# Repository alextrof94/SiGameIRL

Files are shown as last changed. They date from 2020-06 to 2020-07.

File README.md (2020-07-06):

# SiGameIRL 
Устройство для проведения "Своей игры" с использованием "SImulator".

Автор программы для ПК Владимир Хиль: https://vladimirkhil.com/si

На данный момент доступна v0.2, где кнопки игроков вызывают собственные прерывания, из-за чего их отработка происходит мгновенно. 
[_Для подробностей перейдите в папку v2_](/v2)

Возможно будет и v0.3, где я полностью откажусь от Arduino, но маловероятно, так как связка Arduino+STM32 работает отлично...

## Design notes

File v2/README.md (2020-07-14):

# SiGameIRL v0.2
Устройство для проведения "Своей игры" (SIGame) через "SImulator".

Автор программы для ПК Владимир Хиль: https://vladimirkhil.com/si

Это версия 0.2

Тестирование платы:
* https://www.youtube.com/watch?v=EU762Oh5ceg

Игровое тестирование:
* https://www.youtube.com/watch?v=C6XTehjXuXQ

# Что вам потребуется

## Ведущий

* STM32F103C8T6 "Blue pill" (не запаянная) + программатор STLink v2 (желательно для прошивки, работа с другими методами прошивки не гарантируются)
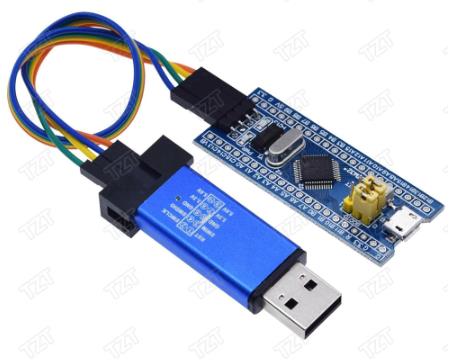
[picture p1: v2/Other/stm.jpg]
<dl></dl>

* Arduino nano (не запаянная)
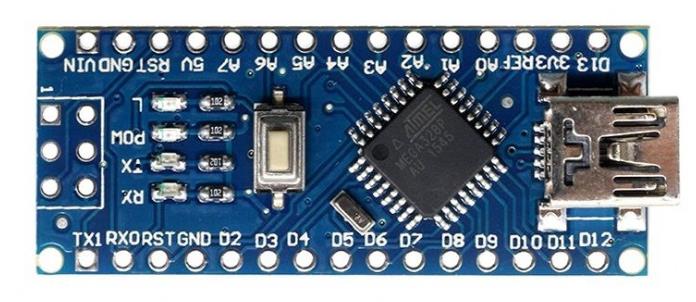
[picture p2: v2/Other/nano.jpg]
<dl></dl>

* Переключатель (опционально; 2 шт, либо 1 шт двухканальный, для разрыва цепи UART для программирования Arduino)

* Max7219 7-сегментный дисплей
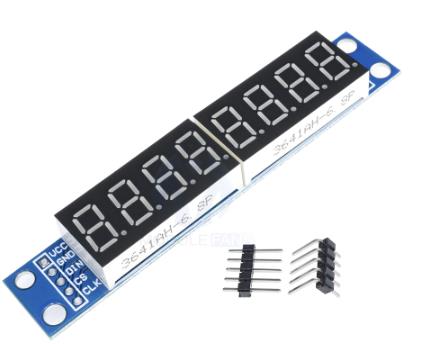
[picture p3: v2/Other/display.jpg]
<dl></dl>

* WS2812B светодиодная лента (60 светодиодов/м, 14 светодиодов с длинной 23.4см; можно также использовать и другую плотность светодиодов, общей длинной 23.4см, количество должно быть четным, например 32 светодиода при плотности 144с/м)
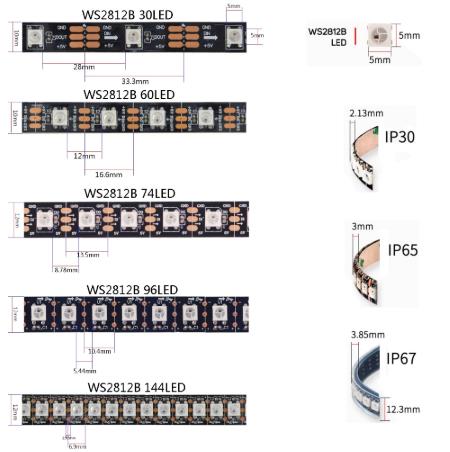
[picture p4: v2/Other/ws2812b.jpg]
<dl></dl>

* Кнопки 12х12мм с крышкой (13 шт)
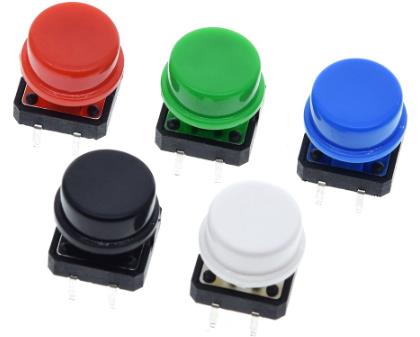
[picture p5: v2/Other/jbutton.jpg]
<dl></dl>

* Фоторезистор
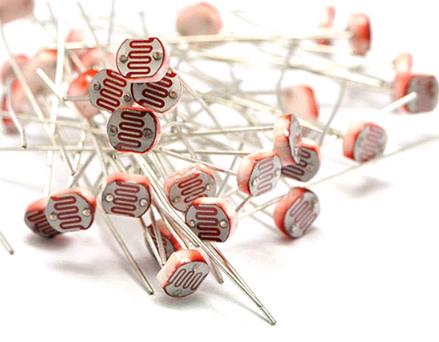
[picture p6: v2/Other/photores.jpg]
<dl></dl>

* Резистор 10000 Ом (11 шт)

* JST 3 pin (8 шт)
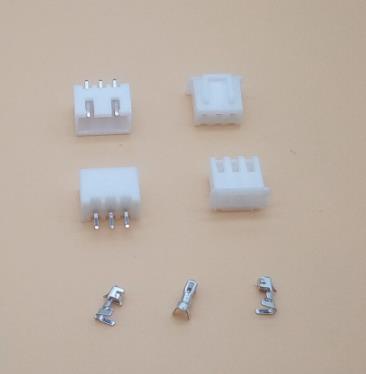
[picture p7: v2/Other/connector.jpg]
<dl></dl>

* Макетная плата (для пайки соединителей игроков) 

* Болты м3 (4 шт 6-12мм)

* Конденсатор электролитический (опционально, для впайки по питанию между +5в и землей)

* Резистор 300-1000 Ом и Светодиод (3 шт; опционально; __в модели нет для них отверстий__)

## Игрок (Умножаем на количество игроков, x8 обычно, но использовать можно и меньше)

* Кнопка 12x12мм (такие же как у судьи, но без крышек)
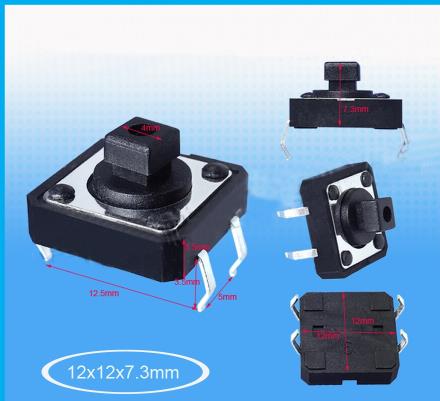
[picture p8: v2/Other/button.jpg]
<dl></dl>

* Резистор 300-1000 Ом

* Светодиоды (3 шт, можно и 1-2шт; цвет не важен; запаиваются параллельно)

* BLS 3 pin

* PLS 3 pin

# Собранный вид

* Собранный вариант (без питания от аккумуляторов)
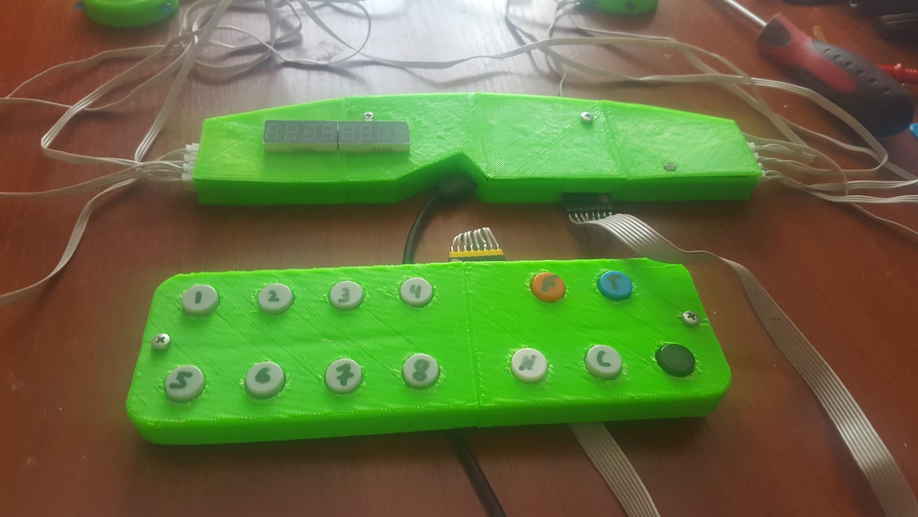
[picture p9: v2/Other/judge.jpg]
<dl></dl>
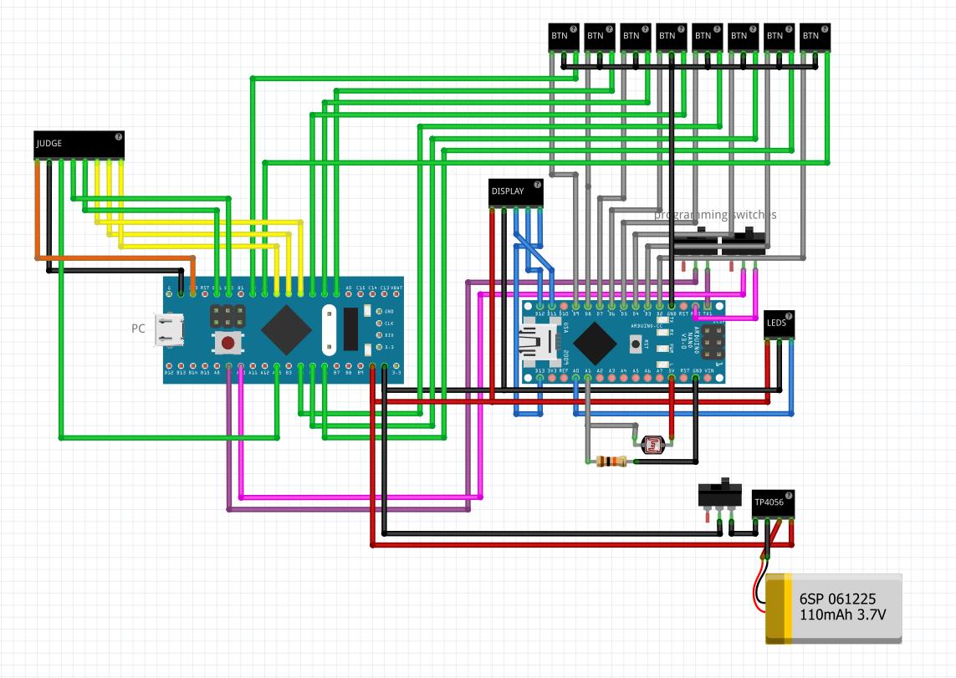
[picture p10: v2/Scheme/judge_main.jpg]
<dl></dl>
Светодиоды на модуле кнопок ведущего опциональны
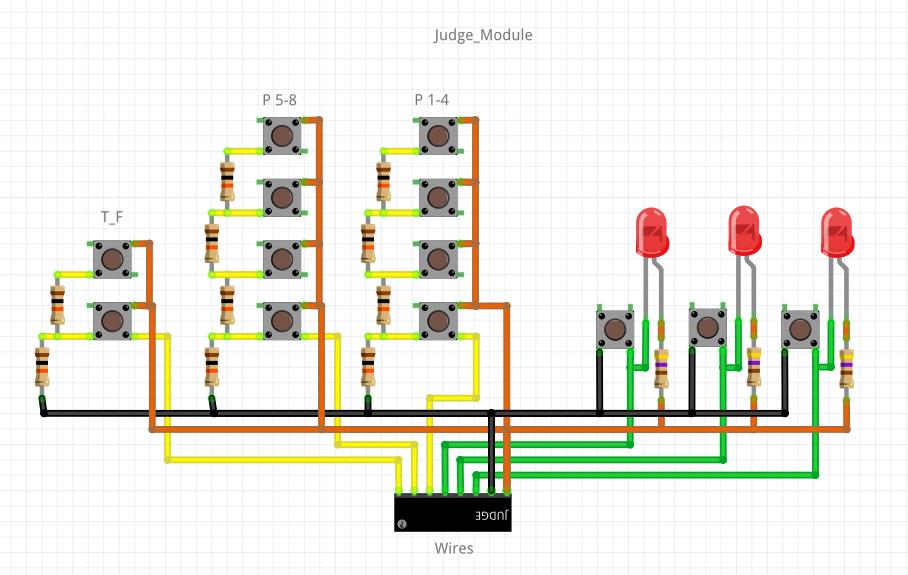
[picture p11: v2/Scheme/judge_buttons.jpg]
<dl></dl>

* Кнопка игрока
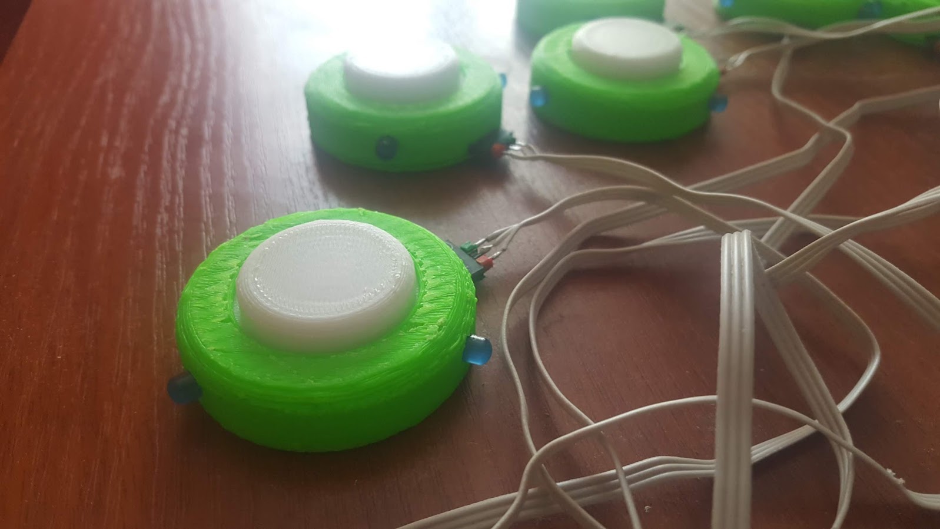
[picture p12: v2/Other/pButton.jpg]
<dl></dl>
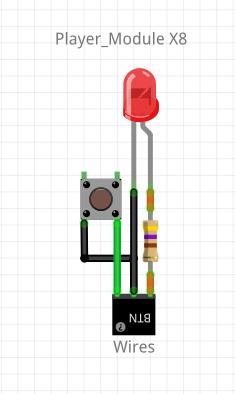
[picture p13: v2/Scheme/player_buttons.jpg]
<dl></dl>

* Внутри
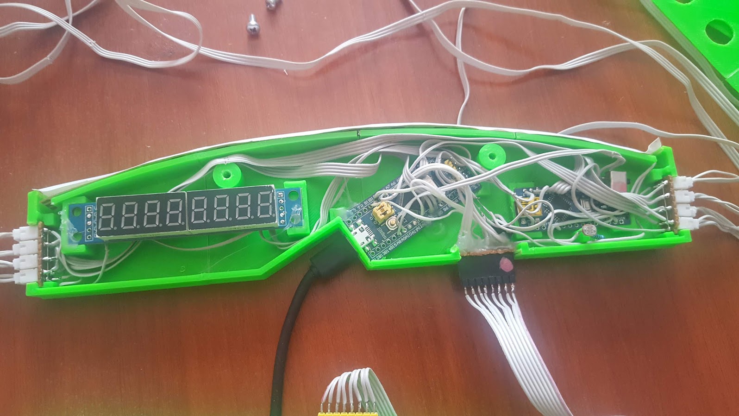
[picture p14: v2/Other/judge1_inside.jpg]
<dl></dl>
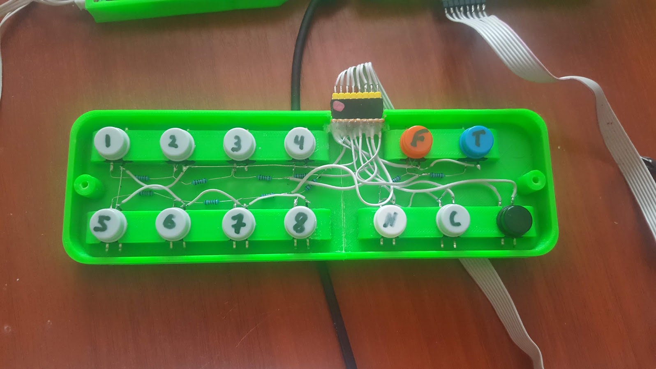
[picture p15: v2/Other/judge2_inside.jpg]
<dl></dl>
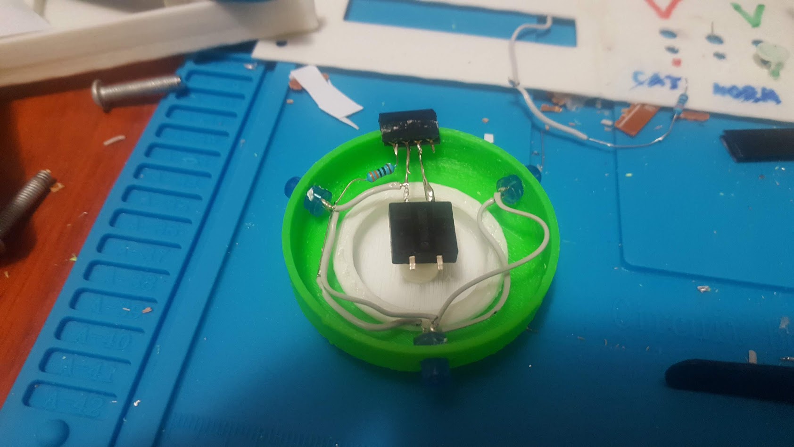
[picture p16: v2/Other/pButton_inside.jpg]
<dl></dl>

# Инструкция по использованию

## Первоначальная настройка

Как только вы подсоединяете питание, проходит проверка соединений (загораются кнопки, дисплей и индикатор). Затем вы переходите в первоначальную настройку, где вас просят ввести: 

* Время на реакцию игроков (когда они могут нажать кнопку для ответа) от 5 до 120 секунд, стандартных 10 секунд обычно достаточно, с привыкшими можно и 5 ставить.
* Время на ответ игрока от 5 до 120 секунд, стандартные 30 секунд для рядового человека - нормальное время, в любом случае, каждый раз ждать по 30 секунд не придется, так как на кнопки True/False можно нажать и во время ответа.
* Время на судейство от 5 до 120 секунд (стд. 120), оно введено для того, чтобы если ответ достаточно трудный и ведущему нужно уточнить что-либо - он может это делать во время судейства, игрок при этом уже должен молчать. 
* Время пенальти при фальшстарте от 0 до 5 секунд (стд. 2). Если игрок кликает свою кнопку до начала отсчета времени реакции - ему назначается штраф в секундах, когда его кнопка не будет реагировать на нажатия.
* Принудительная индексация игроков. В данный момент требуется по очереди нажать кнопки игрокам от 1 до Х, иначе им будут присвоены номера в зависимости от подключений и распайки коннекторов, и может возникнуть путаница. В случае игры со специальной версией СИмулятора - это может внести неразбериху. 

После ввода настроек - вы переходите в режим готовности, из которых вы можете запускать основные режимы игры с их подрежимами.
Также случайным образом выбирается выбирающий игрок. 

## Режимы

Всего есть 3 основных режима:

* Нормальный
* Кот в мешке / Аукцион
* Рандомизатор

Как только вы нажимаете на тему+сумму по выбору игрока вы выясняете какой тип вопроса перед вами, и от этого уже нажимаете Master/Special кнопку.

### Нормальный

1.1. Чтобы запустить нормальный режим - нажмите кнопку Master после прочтения вопроса (проигрывания музыки, отображения картинки).

1.2. После нажатия запустится подрежим реакции игроков. Игроки могут нажать свою кнопку и начать отвечать на вопрос. 

1.3. Если время вышло - вы вернетесь обратно в режим готовности. 

1.4. Если игрок нажал кнопку, то запустится подрежим его ответа, кнопка подсветится, на экране отобразится его индекс. Как только время пройдет - запустится подрежим судейства. Если же судья нажмет кнопку True - данный вопрос прекратится, и право хода перейдет к этому игроку. Если судья нажмет False - продолжится подрежим реакции игроков, но данный игрок не сможет еще раз нажать на кнопку во время этого вопроса.

1.5. Во время подрежима судейства опять же судья может нажать True/False с тем же результатом. И если время судейства вышло, False нажимается автоматически.

### Кот в мешке / Аукцион / Вопрос от спонсора

2.1. Чтобы запустить этот режим - надо нажать кнопку Special, если вы увидели вопрос-аукцион (вопрос со ставкой), кота в мешке (вопрос с секретом) или вопрос от спонсора (вопрос без риска).

2.2. После этого вы переходите в подрежим выбора отвечающего игрока, который осуществляется кнопками 1-8. После выбора игрока нажмите кнопку Master, чтобы перейти в подрежим ответа игрока как в пункте 1.4. только в случае с нажатием кнопки False судьей - вопрос тоже прекратится, и право выбора также перейдет к отвечавшему игроку.

### Рандомизатор

3.1. При удержании кнопки Reserved в течении секунды вы перейдете в режим рандомизации. Сначала от вас требуется выбрать игроков, которые участвуют в рандомизации при помощи кнопок 1-8. 

3.2. При нажатии кнопки Master из этих игроков случайно выбирается один. Если вы хотите передать ход этому игроку - нажмите кнопку True, иначе - нажмите False. При нажатии True/False вы автоматически перейдете в режим готовности.

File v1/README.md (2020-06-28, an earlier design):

# SiGameIRL
Устройство для проведения "Своей игры" (SIGame) через "SImulator".

Автор программы для ПК Владимир Хиль: https://vladimirkhil.com/si

Это версия 0.1. К сборке __НЕ рекомендуется__. Скоро займусь версией 0.2, где будут учтены проблемы данной версии. В данный момент нажатия кнопок считываются в цикле и бывают моменты, когда два игрока одновременно нажимают кнопки (период между считываниями кнопок 50-100 микросекунд), в видео тестирования в описании можно найти такой момент. 

Вторая версия будет основана на базе STM32F103C8T6 Blue Pill. Все кнопки будут иметь собственное прерывание (мгновенное отрабатывание).

Тестирование платы:
* https://www.youtube.com/watch?v=pi8g3aP3nV4

SiGameIRL собранный (тестирование в игре с 5-ю участниками; там маты, так что 16+):
* https://www.youtube.com/watch?v=th2ahZnA1qU

# Что вам потребуется

## Ведущий

### Для использования с питанием от ПК или блока питания

* Arduino nano (не запаянная)
<dl></dl>

* Max7219 7-сегментный дисплей
<dl></dl>

* WS2812B светодиодная лента (60 светодиодов/м, 10 светодиодов с длинной 16.7см, можно также использовать и другую плотность светодиодов, общей длинной 16.7см)
<dl></dl>

* Кнопки 6x6мм с длинным штоком (3 шт)
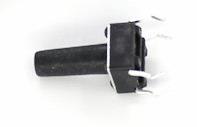
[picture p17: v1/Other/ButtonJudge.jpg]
<dl></dl>

* Резисторы 100-1000 Ом (3 шт)

* Светодиоды (3 шт; желательно красный-желтый-зеленый)

* Макетная плата (для пайки кнопок ведущего и соединителей игроков) 

* Болты м3 (4 шт 6-12мм)

### Для автономного питания от аккумуляторов 18650

* TP4056 с защитой
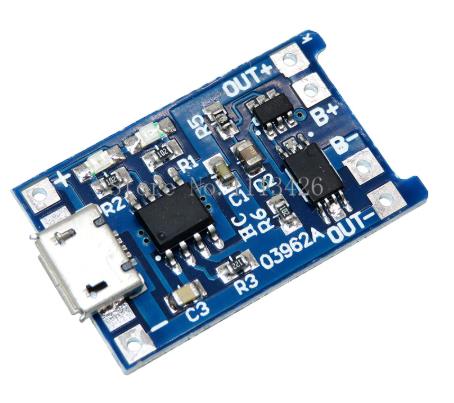
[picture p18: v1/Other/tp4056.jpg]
<dl></dl>

* 18650 держатель (1-2 шт; запаиваются ПАРАЛЛЕЛЬНО)
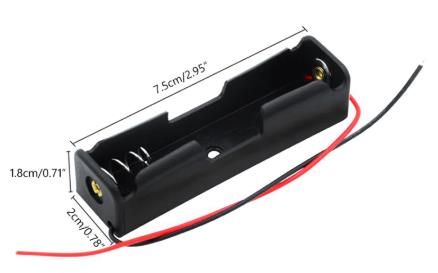
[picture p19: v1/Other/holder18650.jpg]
<dl></dl>

* Выключатель (10x15мм)
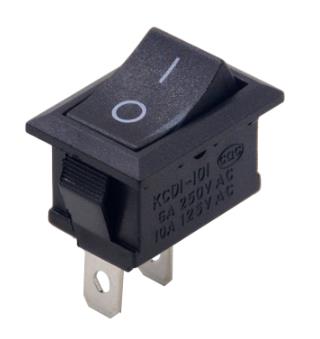
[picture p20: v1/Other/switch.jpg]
<dl></dl>

* Болты м3 (2 шт 6-20мм)

## Игрок (Умножаем на количество игроков, x8 обычно, но использовать можно и меньше)

* Кнопка 12x12mm
<dl></dl>

* Резистор 100-1000 Ом

* Светодиоды (3 шт, можно и 1-2шт; цвет не важен; запаиваются параллельно)

* JST 3 pin
<dl></dl>

* BLS 3 pin

* PLS 3 pin

# Собранный вид

* Собранный вариант (без питания от аккумуляторов)
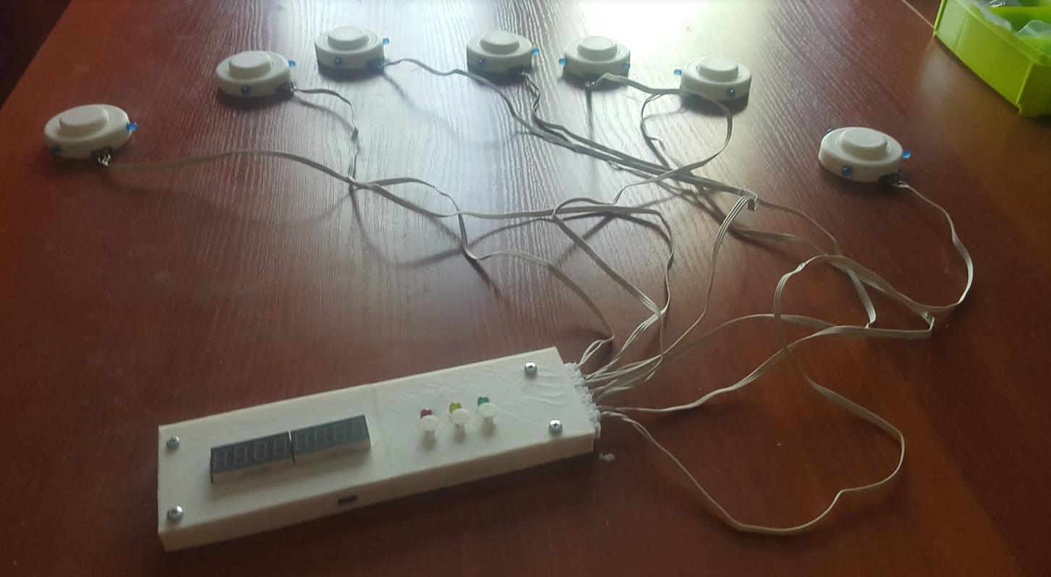
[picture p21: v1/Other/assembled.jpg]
<dl></dl>
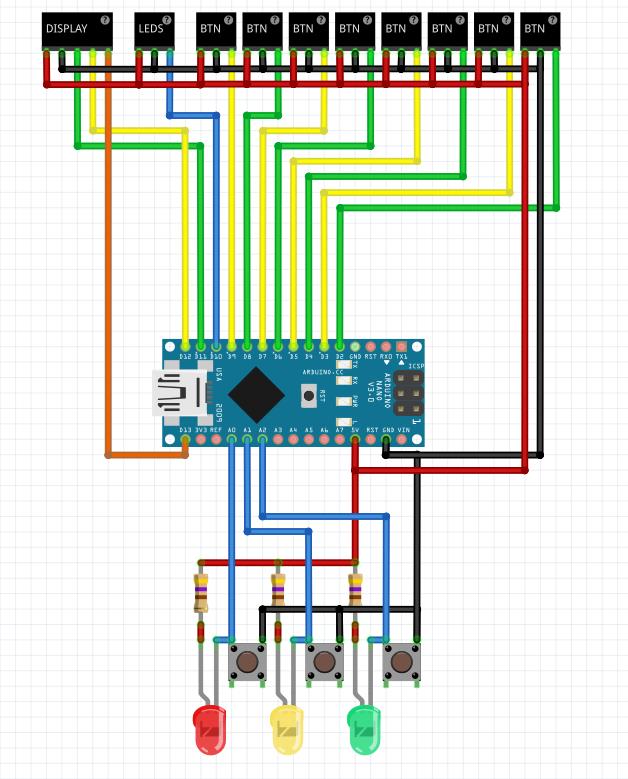
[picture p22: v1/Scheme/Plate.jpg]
<dl></dl>

* Кнопка игрока
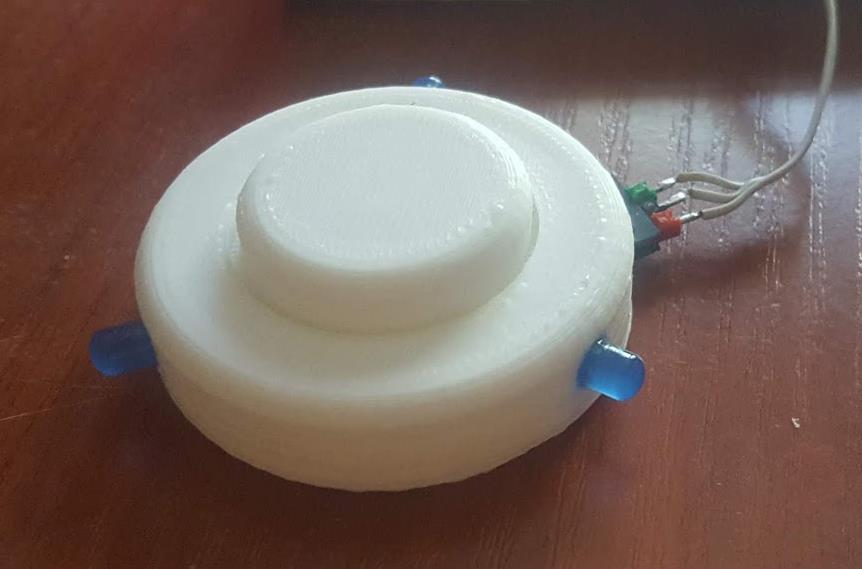
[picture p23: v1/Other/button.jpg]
<dl></dl>
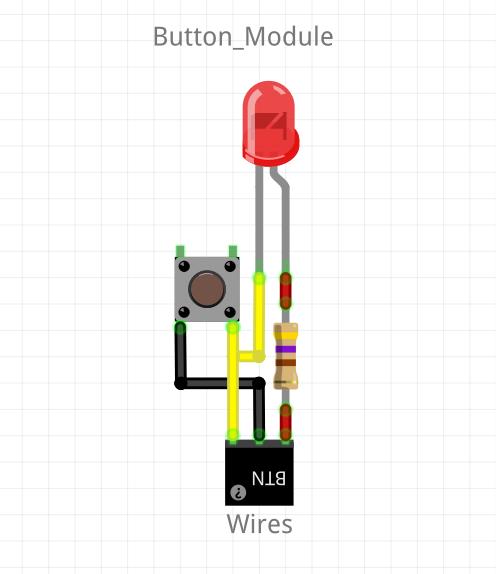
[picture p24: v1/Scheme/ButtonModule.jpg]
<dl></dl>

* Внутри
<dl></dl>

* Соединители игроков
<dl></dl>

* Кнопки ведущего
<dl></dl>

Все кнопки (сейчас) работают по следующей схеме: 
<dl></dl>

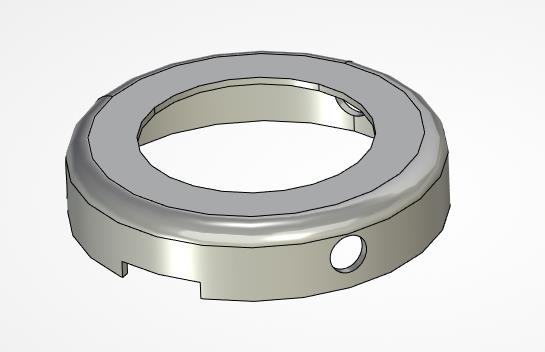
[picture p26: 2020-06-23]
v2/Models/Button/PartMiddle.jpg

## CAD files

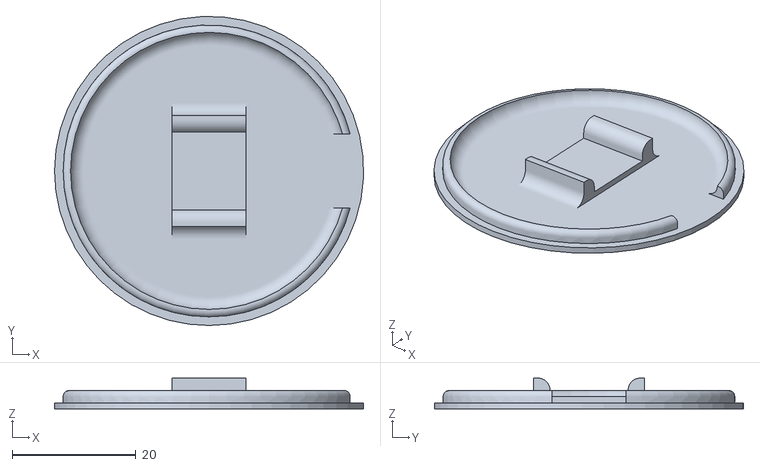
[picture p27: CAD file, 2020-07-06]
v2/Models/Button/SiGame_Button_B.stl
50.0 x 50.0 x 5.00

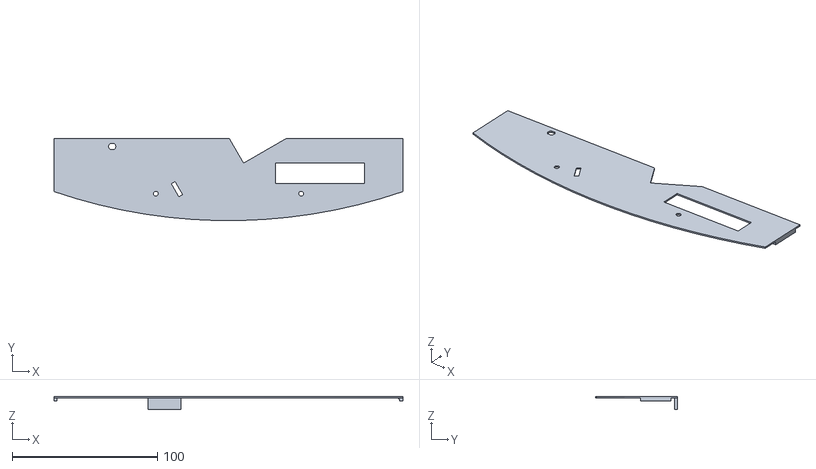
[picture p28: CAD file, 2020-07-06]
v2/Models/Judge/JudgeMaster_T.stl
240.0 x 56.4 x 9.19

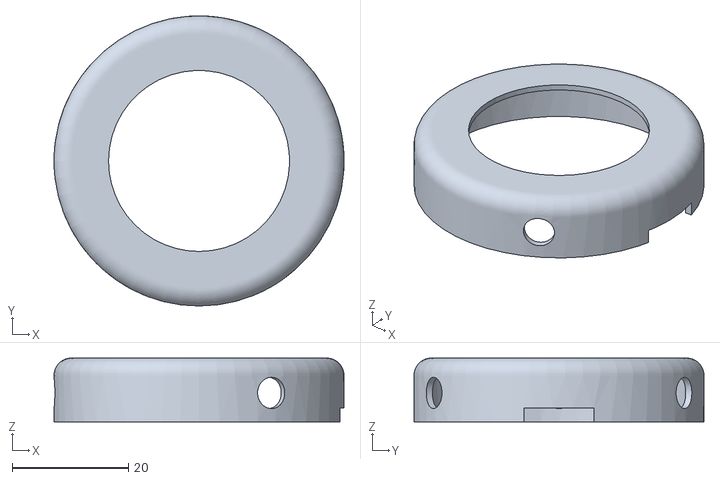
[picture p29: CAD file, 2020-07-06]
v2/Models/Button/SiGame_Button_M.stl
50.0 x 50.0 x 11.0

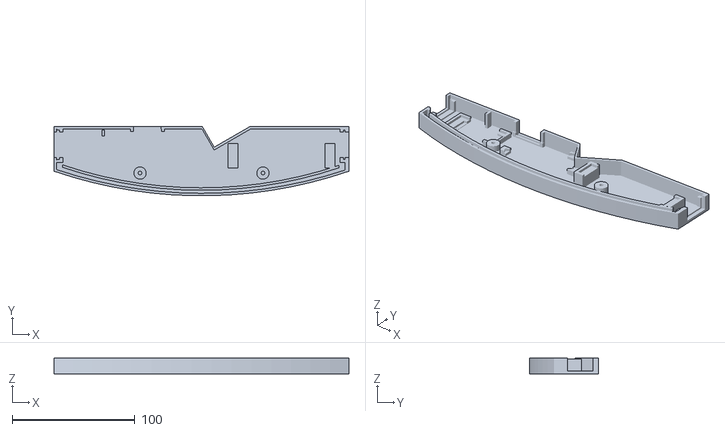
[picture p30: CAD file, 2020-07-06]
v2/Models/Judge/JudgeMaster_B.stl
240.0 x 56.4 x 13.0

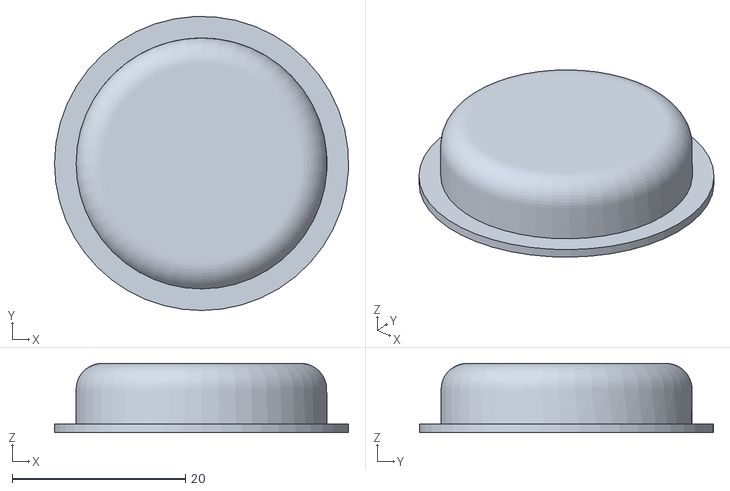
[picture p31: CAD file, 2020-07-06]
v2/Models/Button/SiGame_Button_T.stl
34.0 x 34.0 x 8.00

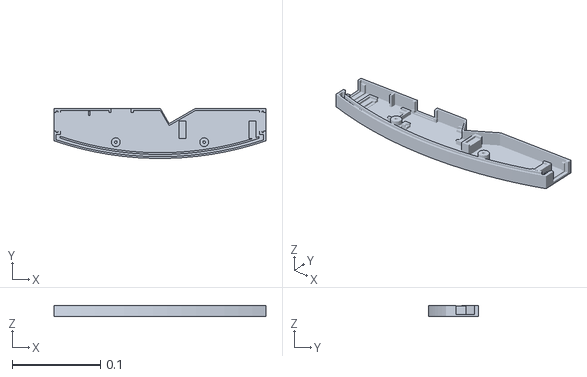
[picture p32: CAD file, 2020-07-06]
v2/Models/Judge/JudgeMaster.obj
0.24 x 0.0564 x 0.013

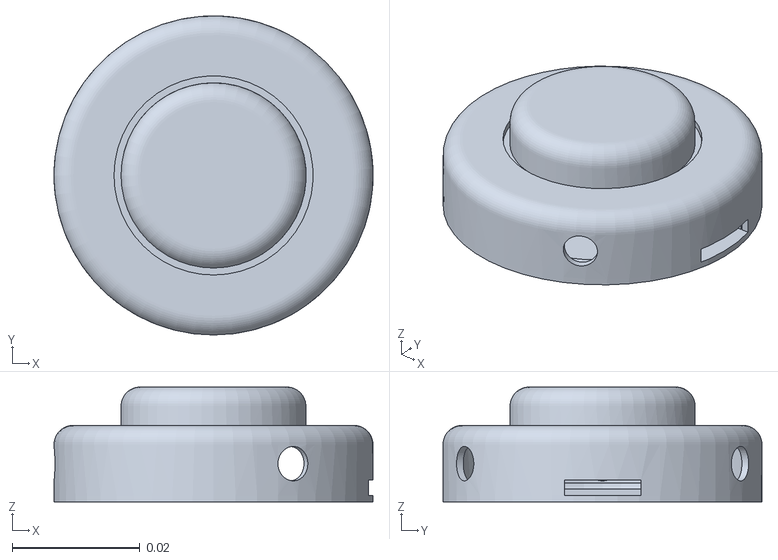
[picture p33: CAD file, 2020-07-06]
v2/Models/Button/SiGame_Button.obj
0.05 x 0.05 x 0.018

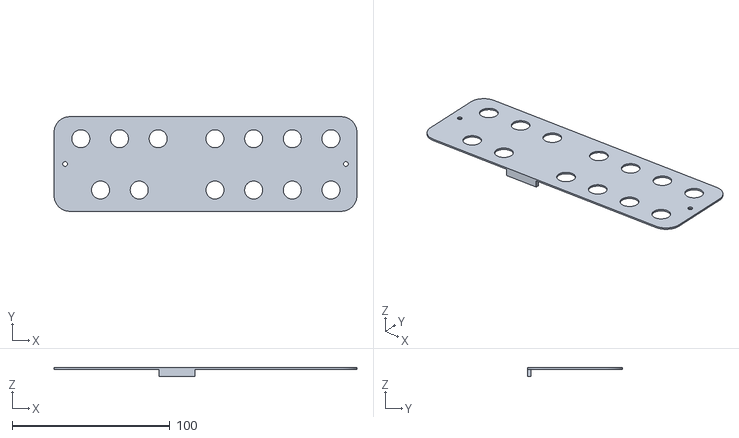
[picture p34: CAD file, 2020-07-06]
v2/Models/Judge/JudgeButtons_T.stl
192.0 x 60.0 x 5.40

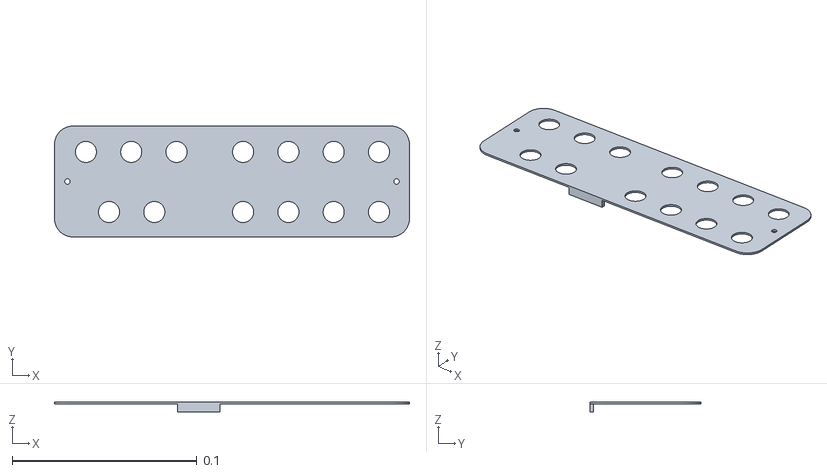
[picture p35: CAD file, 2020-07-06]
v2/Models/Judge/JudgeButtons.obj
0.192 x 0.06 x 0.0054

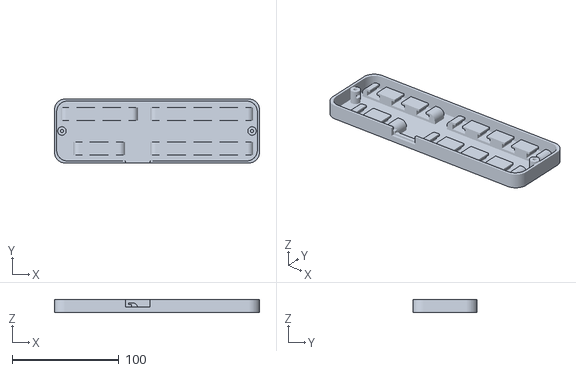
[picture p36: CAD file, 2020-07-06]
v2/Models/Judge/JudgeButtons_B.stl
192.0 x 60.0 x 12.0

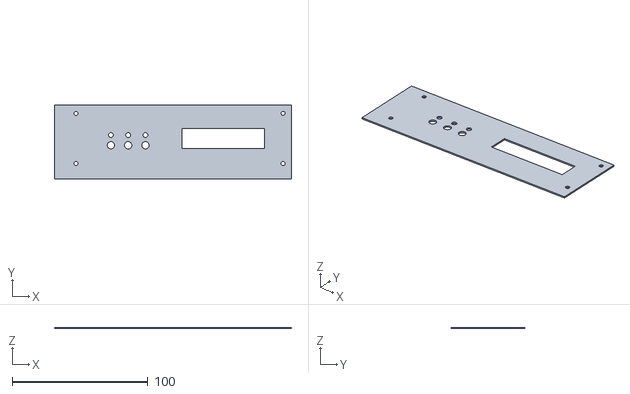
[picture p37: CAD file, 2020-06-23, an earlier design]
v1/Models/Judge/SiGame_Judge_Top.stl
174.4 x 54.6 x 1.00

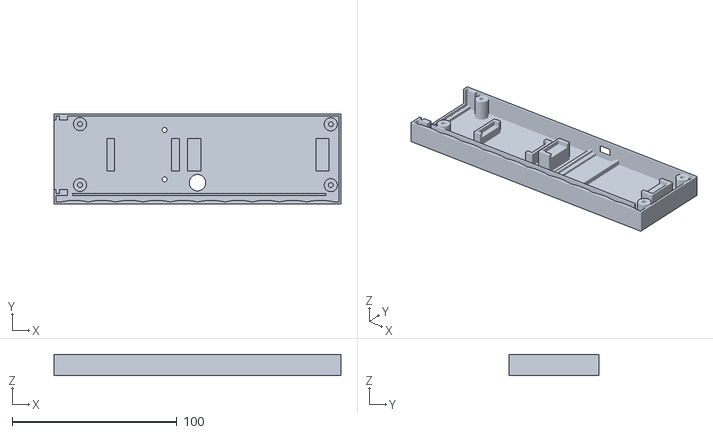
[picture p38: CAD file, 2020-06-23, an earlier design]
v1/Models/Judge/SiGame_Judge_Bottom.stl
174.4 x 54.6 x 13.0

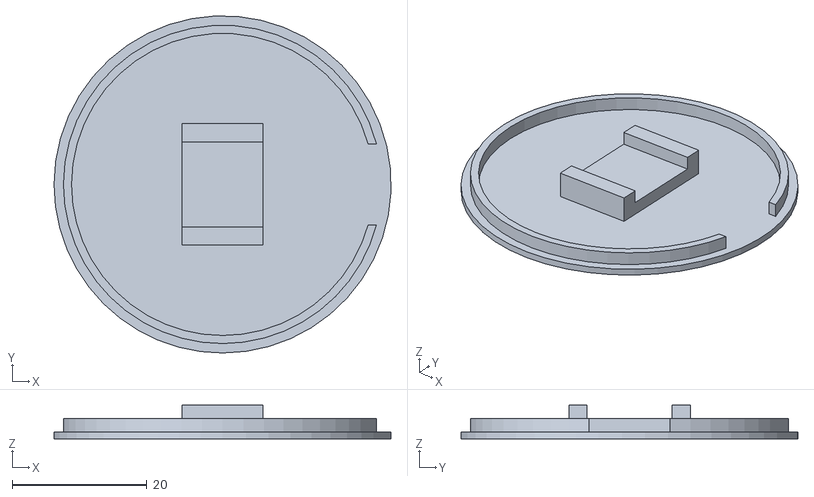
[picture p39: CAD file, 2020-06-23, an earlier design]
v1/Models/Button/SiGame_Button_Bottom.stl
50.0 x 50.0 x 5.00

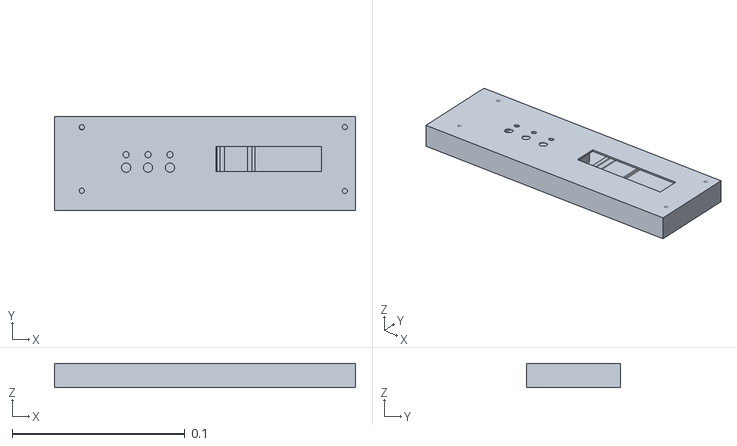
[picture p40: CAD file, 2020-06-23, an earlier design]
v1/Models/Judge/SiGame_Judge.obj
0.174 x 0.0546 x 0.014

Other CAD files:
v1/Models/Button/SiGame_Button_Middle.stl
v1/Models/Button/SiGame_Button_Top.stl
v1/Models/Button/SiGame_Button.obj
v1/Models/Judge/SiGame_Judge_Accum.stl
v1/Models/Button/SiGame_Button.dxf
v1/Models/Judge/SiGame_Judge.dxf
v2/Models/Button/SiGame_Button.dxf
v2/Models/Judge/JudgeButtons.dxf
v2/Models/Judge/JudgeMaster.dxf

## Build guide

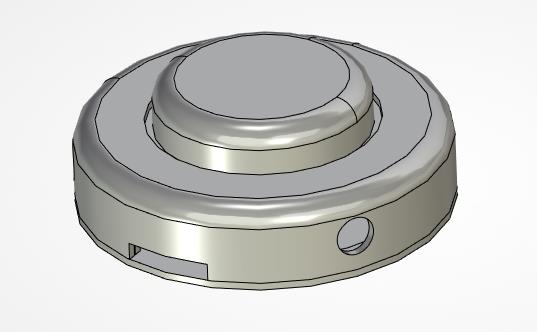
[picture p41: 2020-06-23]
v2/Models/Button/Assembled.jpg

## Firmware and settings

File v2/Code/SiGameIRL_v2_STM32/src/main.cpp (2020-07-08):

#include <Arduino.h>

const uint8_t PIN_PLAYERS[8] = {PB0, PA1, PA2, PA3, PB4, PB5, PB6, PA7}; // !!! SETUP THIS WITH YOUR SOLDERED BUTTONS (MUST BE IN PB0, PA1, PA2, PA3, PB4, PB5, PB6, PA7)

const uint8_t PIN_JUDGE_MASTER = PA15; // !!! SETUP THIS WITH YOUR SOLDERED BUTTONS (MUST BE IN PB10, PB11, PA15)
const uint8_t PIN_JUDGE_SPECIAL = PB10; // !!! SETUP THIS WITH YOUR SOLDERED BUTTONS (MUST BE IN PB10, PB11, PA15)
const uint8_t PIN_JUDGE_RESERVED = PB11; // !!! SETUP THIS WITH YOUR SOLDERED BUTTONS (MUST BE IN PB10, PB11, PA15)
const uint8_t PIN_JUDGE_A_T_F = PA6; // !!! SETUP THIS WITH YOUR SOLDERED BUTTONS (MUST BE IN PA4, PA5, PA6)
const uint8_t PIN_JUDGE_A_P_1_4 = PA4; // !!! SETUP THIS WITH YOUR SOLDERED BUTTONS (MUST BE IN PA4, PA5, PA6)
const uint8_t PIN_JUDGE_A_P_5_8 = PA5; // !!! SETUP THIS WITH YOUR SOLDERED BUTTONS (MUST BE IN PA4, PA5, PA6)

#define PC Serial
const uint32_t PC_BAUDTRATE = 115200;
#define ARD Serial1
const uint32_t ARD_BAUDTRATE = 115200;

#define COLOR_QUESTION 0x6600FF // purple
#define COLOR_ANSWERING 0x0000FF // blue 
#define COLOR_JUDGEMENT 0xFFFF00 // yellow
#define COLOR_ANSWER_TRUE 0x00FF00 // green
#define COLOR_ANSWER_FALSE 0xFF0000 // red

#define MODE_INITIALIZATION 100
#define MODE_SETTINGS 0
#define MODE_READY 1
#define MODE_QUESTION_NORMAL 2
#define MODE_QUESTION_CAT_SELECT_PLAYER 3
#define MODE_ANSWERING 6
#define MODE_JUDGEMENT 7
#define MODE_ROUND_END 8
#define MODE_RANDOM_SELECTING_PLAYERS 20
#define MODE_RANDOM_DO 21
uint8_t mode = MODE_INITIALIZATION;
bool isCatQuestion = false;
uint8_t modeOld = 255;
int answeringPlayer = -1;
int answeringPlayerOld = -1;

#define ROUND_END_STATUS_TIME_IS_UP 0
#define ROUND_END_STATUS_SKIPPED 1
#define ROUND_END_STATUS_ANSWERED 2
#define ROUND_END_STATUS_CAT_FALSE 3
uint8_t roundEndStatus = ROUND_END_STATUS_TIME_IS_UP;

class Button {
  protected:
    bool isPressedOld = false;
  public:
    uint8_t pin;  
    bool isPressed = false;
    bool isClicked = false;
    uint32_t pressTime = 0;
    uint32_t releaseTime = 0;
    uint32_t debounceTime = 50000; // 50 ms

    Button() {}

    void readState() {
      if (isPressed && !isPressedOld) {
        pressTime = micros();
      } else {
        if (!isPressed && isPressedOld) {
          releaseTime = micros();
          if (releaseTime - pressTime > debounceTime)
            isClicked = true;
        }
      }
      
      isPressedOld = isPressed;
    }

    bool clickNotProcessed() {
      if (isClicked) {
        isClicked = false;
        return true;
      } else
        return false;      
    };
};

class ButtonInterrupt: public Button {
  public:
    ButtonInterrupt() : Button() {}
    ButtonInterrupt(uint8_t inPin) {
      pin = inPin;
    };

    void readState() {
      isPressed = !digitalRead(pin);
      Button::readState();
    };

};

class ButtonAnalog : public Button {  
  private:
    uint16_t buf;
  public:
    uint16_t analogMin;
    uint16_t analogMax;

    ButtonAnalog() : Button() {}
    ButtonAnalog(uint8_t inPin, uint16_t inValueMin, uint16_t inValueMax) {
      pin = inPin;
      analogMin = inValueMin;
      analogMax = inValueMax;
    };

    void readState() {
      buf = analogRead(pin);
      if (buf >= analogMin && buf <= analogMax)
        isPressed = true;
      else
        isPressed = false;

      Button::readState();
    };
};

class Player {
  public:
    ButtonInterrupt button;
    uint32_t falseStartPenaltyTimer = 0;
    bool falseStartPenalty = false;
    bool canAnswer = false;
    uint8_t playerIndex = 255;
    uint8_t playerActive = false;

    Player() {};

    void reset() {
      canAnswer = true;
      falseStartPenalty = false;
    }
};
Player players[8];
uint8_t activePlayerCount = 0;

ButtonInterrupt jbtnMaster = ButtonInterrupt(PIN_JUDGE_MASTER);
ButtonInterrupt jbtnSpecial = ButtonInterrupt(PIN_JUDGE_SPECIAL);
ButtonInterrupt jbtnReserved = ButtonInterrupt(PIN_JUDGE_RESERVED);
ButtonAnalog jbtnTrue = ButtonAnalog(PIN_JUDGE_A_T_F, 400, 620);
ButtonAnalog jbtnFalse = ButtonAnalog(PIN_JUDGE_A_T_F, 900, 1023);
ButtonAnalog jbtnPS[8] = {
  ButtonAnalog(PIN_JUDGE_A_P_1_4, 200, 290),
  ButtonAnalog(PIN_JUDGE_A_P_1_4, 290, 480),
  ButtonAnalog(PIN_JUDGE_A_P_1_4, 480, 700),
  ButtonAnalog(PIN_JUDGE_A_P_1_4, 700, 1023),
  ButtonAnalog(PIN_JUDGE_A_P_5_8, 200, 290),
  ButtonAnalog(PIN_JUDGE_A_P_5_8, 290, 480),
  ButtonAnalog(PIN_JUDGE_A_P_5_8, 480, 700),
  ButtonAnalog(PIN_JUDGE_A_P_5_8, 700, 1023)
};


const uint32_t questionSecondsMax = 120;
uint32_t questionSeconds = 10;
uint32_t questionSecondsLeft;
uint32_t questionMsTimer;
uint32_t questionMsTimerLeft;

const uint32_t answerSecondsMax = 120;
uint32_t answerSeconds = 30;
uint32_t answerSecondsLeft;
uint32_t answerMsTimer;

const uint32_t judgeSecondsMax = 120;
uint32_t judgeSeconds = 120;
uint32_t judgeSecondsLeft;
uint32_t judgeMsTimer;

const uint32_t falseStartPenaltySecondsMax = 5;
uint32_t falseStartPenaltySeconds = 2;
bool falseStartPenaltyEnabled = true;
uint32_t falseStartPenaltyDelay = 2000;

void processPlayer(uint8_t playerIndex) {
  players[playerIndex].button.isPressed = !digitalRead(PIN_PLAYERS[playerIndex]);
  if (players[playerIndex].button.isPressed) {
    players[playerIndex].button.pressTime = micros();
    if (mode == MODE_READY) {
      if (falseStartPenaltyEnabled) {
        players[playerIndex].falseStartPenalty = true;
        players[playerIndex].falseStartPenaltyTimer = millis() + falseStartPenaltyDelay;
      }
    } else
    if (mode == MODE_QUESTION_NORMAL) {
      if (answeringPlayer == -1) {
        if (!players[playerIndex].falseStartPenalty && players[playerIndex].canAnswer)
          answeringPlayer = playerIndex; // attention
      }
    } else
    if (mode == MODE_ANSWERING || mode == MODE_JUDGEMENT)
    {
      if (falseStartPenaltyEnabled && answeringPlayer != playerIndex) { // attention
        players[playerIndex].falseStartPenalty = true;
        players[playerIndex].falseStartPenaltyTimer = millis() + falseStartPenaltyDelay;
      }
    }    
  }
  else {
    players[playerIndex].button.releaseTime = micros();
    players[playerIndex].button.isClicked = true;
  }
}

void P0_INT() {
  processPlayer(0);
}
void P1_INT() {
  processPlayer(1);
}
void P2_INT() {
  processPlayer(2);
}
void P3_INT() {
  processPlayer(3);
}
void P4_INT() {
  processPlayer(4);
}
void P5_INT() {
  processPlayer(5);
}
void P6_INT() {
  processPlayer(6);
}
void P7_INT() {
  processPlayer(7);
}

void JMASTER_INT() {
  jbtnMaster.readState();
}
void JSPECIAL_INT() {
  jbtnSpecial.readState();
}
void JRESERVED_INT() {
  jbtnReserved.readState();
}

void jbuttonsCheck() {
  jbtnTrue.readState();
  jbtnFalse.readState();
  for (uint8_t i = 0; i < 8; i++)
    jbtnPS[i].readState();
}

void sendToLeds(uint8_t needToLight, uint32_t color) {
  ARD.print('L');
  ARD.print((char)needToLight);
  ARD.print((char)((color >> 16) & 0xFF));
  ARD.print((char)((color >> 8) & 0xFF));
  ARD.println((char)(color & 0xFF));
}
void sendText(String str) {
  ARD.print('T');
  ARD.println(str);
}
void sendReset() {
  ARD.println('R');
}
void sendPlayer(uint8_t p, char state){
  ARD.print('P');
  ARD.print((char)p);
  ARD.println(state);
}


bool rEnable = true;
uint32_t displayUpdateTimer;
const uint32_t displayUpdateDelay = 1000; // ms
uint32_t ledsUpdateTimer;
uint32_t ledsUpdateDelay;

uint8_t ledstripLength = 0;
uint8_t initNeed = 1;
void modeInitialization() {
  if (ARD.available() > 3) {
    char cmd = ARD.read();
    if (cmd == 'L') {
      uint8_t k = 100;
      for (uint8_t i = 0; i < 3; i++) {
        ledstripLength += (ARD.read() - '0') * k;
        k /= 10;
      }
      initNeed--;
      ARD.print('K');
      PC.print("Log: ledstrip length "); PC.println(ledstripLength);
    }  
  }
  if (initNeed == 0) {
    mode = MODE_SETTINGS;
    digitalWrite(PC13, 0);
  }
}

uint8_t modeSettingsStage = 0;
bool modeSettingsUpdateDisplay = true;
uint8_t playerIndex = 0;
void modeSettings() {
  jbuttonsCheck();
  switch (modeSettingsStage) {
    case 0: 
      if (modeSettingsUpdateDisplay) {
        modeSettingsUpdateDisplay = false;
        String str = "Cntdn   ";
        str[5] = (questionSeconds / 100)+'0';
        str[6] = ((questionSeconds / 10) % 10)+'0';
        str[7] = (questionSeconds % 10)+'0';
        sendText(str);
      }
      if (jbtnTrue.clickNotProcessed()) {
        questionSeconds += 5;
        if (questionSeconds > questionSecondsMax)
          questionSeconds = questionSecondsMax;
        modeSettingsUpdateDisplay = true;
      }
      if (jbtnFalse.clickNotProcessed()) {
        questionSeconds -= 5;
        if (questionSeconds < 5)
          questionSeconds = 5;
        modeSettingsUpdateDisplay = true;
      }
      if (jbtnMaster.clickNotProcessed()) {
        modeSettingsStage++;
        modeSettingsUpdateDisplay = true;
      }
      break;
    case 1: 
      if (modeSettingsUpdateDisplay) {
        modeSettingsUpdateDisplay = false;
        String str = "AnS     ";
        str[5] = (answerSeconds / 100)+'0';
        str[6] = ((answerSeconds / 10) % 10)+'0';
        str[7] = (answerSeconds % 10)+'0';
        sendText(str);
      }
      if (jbtnTrue.clickNotProcessed()) {
        answerSeconds += 5;
        if (answerSeconds > answerSecondsMax)
          answerSeconds = answerSecondsMax;
        modeSettingsUpdateDisplay = true;
      }
      if (jbtnFalse.clickNotProcessed()) {
        answerSeconds -= 5;
        if (answerSeconds < 5)
          answerSeconds = 5;
        modeSettingsUpdateDisplay = true;
      }
      if (jbtnMaster.clickNotProcessed()) {
        modeSettingsStage++;
        modeSettingsUpdateDisplay = true;
      }
      break;
    case 2: 
      if (modeSettingsUpdateDisplay) {
        modeSettingsUpdateDisplay = false;
        String str = "JudgE   ";
        str[5] = (judgeSeconds / 100)+'0';
        str[6] = ((judgeSeconds / 10) % 10)+'0';
        str[7] = (judgeSeconds % 10)+'0';
        sendText(str);
      }
      if (jbtnTrue.clickNotProcessed()) {
        judgeSeconds += 5;
        if (judgeSeconds > judgeSecondsMax)
          judgeSeconds = judgeSecondsMax;
        modeSettingsUpdateDisplay = true;
      }
      if (jbtnFalse.clickNotProcessed()) {
        judgeSeconds -= 5;
        if (judgeSeconds < 5)
          judgeSeconds = 5;
        modeSettingsUpdateDisplay = true;
      }
      if (jbtnMaster.clickNotProcessed()) {
        modeSettingsStage++;
        modeSettingsUpdateDisplay = true;
      }
      break;
    case 3: 
      if (modeSettingsUpdateDisplay) {
        modeSettingsUpdateDisplay = false;
        String str = "PEn     ";
        str[7] = falseStartPenaltySeconds +'0';
        sendText(str);
      }
      if (jbtnTrue.clickNotProcessed()) {
        falseStartPenaltySeconds += 1;
        if (falseStartPenaltySeconds > falseStartPenaltySecondsMax)
          falseStartPenaltySeconds = falseStartPenaltySecondsMax;
        modeSettingsUpdateDisplay = true;
      }
      if (jbtnFalse.clickNotProcessed()) {
        if (falseStartPenaltySeconds > 0)
          falseStartPenaltySeconds -= 1;
        falseStartPenaltyEnabled = !(falseStartPenaltySeconds == 0);
        modeSettingsUpdateDisplay = true;
      }
      if (jbtnMaster.clickNotProcessed()) {
        modeSettingsStage++;
        modeSettingsUpdateDisplay = true;
      }
      break;
    case 4:
      if (modeSettingsUpdateDisplay) {
        modeSettingsUpdateDisplay = false;
        String str = "PLAYErS. ";
        str[8] = playerIndex +'0';
        sendText(str);
      }
      for (uint8_t i = 0; i < 8; i++) {
        if (!players[i].playerActive && players[i].button.clickNotProcessed()) {
          players[i].playerActive = true;
          players[i].playerIndex = playerIndex;
          sendPlayer(i, 'F');
          playerIndex++;
          modeSettingsUpdateDisplay = true;
        }
      }
      if (jbtnMaster.clickNotProcessed()) {
        for (uint8_t i = 0; i < 8; i++){
          if (players[i].playerActive)
            activePlayerCount++;
        }
        if (activePlayerCount == 0) {
          activePlayerCount = 8;
          for (uint8_t i = 0; i < 8; i++) {
            players[i].playerActive = true;
            players[i].playerIndex = playerIndex;
            playerIndex++;
          }
        }
        for (uint8_t i = 0; i < 8; i++) {
          if (!players[i].playerActive) {
            players[i].playerIndex = playerIndex;
            playerIndex++;
          }
        }
        randomSeed(micros());
        modeSettingsStage++;
        modeSettingsUpdateDisplay = true;
      }
      break;
  }
  if (modeSettingsStage == 5) {
    modeSettingsStage = 0;
    mode = MODE_READY;
    rEnable = true;
  }
}

void falsestartWork() {
  if (falseStartPenaltyEnabled) {
    for (uint8_t i = 0; i < 8; i++) {
      if (players[i].falseStartPenalty && millis() > players[i].falseStartPenaltyTimer) {
        players[i].falseStartPenalty = false;
      }
    }
  }
}

void blinking(uint32_t color) {
  for (uint8_t j = 0; j < 5; j++) {
    sendToLeds(ledstripLength, color);
    delay(100);
    sendToLeds(0, 0);
    delay(100);
  }
}

uint32_t buttonBattleTimer;
const uint32_t buttonBattleDelay = 100;
void modeReady() {
  if (rEnable) {
    rEnable = false;
    sendReset();
    if (answeringPlayerOld == -1) {
      bool rndGreat = false;
      while (!rndGreat){
        answeringPlayerOld = random(0, 7);
        if (players[answeringPlayerOld].playerActive)
          rndGreat = true;
      }
    }
    sendPlayer(answeringPlayerOld, 'B');
    jbtnMaster.clickNotProcessed();
    jbtnSpecial.clickNotProcessed();
    jbtnReserved.clickNotProcessed();
    String str = "rEAdY   ";
    str[7] = players[answeringPlayerOld].playerIndex +'1';
    sendText(str);
    for (uint8_t i = 0; i < 8; i++) {
      players[i].reset();
    }
  }
  if (jbtnMaster.clickNotProcessed()) {
    mode = MODE_QUESTION_NORMAL;
    isCatQuestion = false;
    rEnable = true;
    questionMsTimer = questionSeconds * 1000 + millis() - 1;
    ledsUpdateDelay = (questionSeconds * 1000) / ledstripLength;
    buttonBattleTimer = millis() + buttonBattleDelay;
    sendReset();
  }
  if (jbtnSpecial.clickNotProcessed()) {
    mode = MODE_QUESTION_CAT_SELECT_PLAYER;
    isCatQuestion = true;
    rEnable = true;
    sendReset();
  }
  if (jbtnReserved.clickNotProcessed()){
    if (jbtnReserved.releaseTime - jbtnReserved.pressTime > 1000000) {
      mode = MODE_RANDOM_SELECTING_PLAYERS;
      rEnable = true;
    }
  }
  falsestartWork();
}

void modeQuestionNormal() {
  // leds work
  if (millis() >= ledsUpdateTimer) {
    ledsUpdateTimer = millis() + ledsUpdateDelay;
    uint8_t ledsNeedLight = ((questionMsTimer - millis()) / (questionSeconds * 10) * ledstripLength) / 100 + 1;
    if (ledsNeedLight > ledstripLength)
      ledsNeedLight = ledstripLength;
    sendToLeds(ledsNeedLight, COLOR_QUESTION);
  }
  // display work
  if (millis() >= displayUpdateTimer) {
    displayUpdateTimer = millis() + displayUpdateDelay;
    questionSecondsLeft = (questionMsTimer - millis()) / 1000;
    String str = "Cnt.dn.   ";
    str[7] = (questionSecondsLeft / 100)+'0';
    str[8] = ((questionSecondsLeft / 10) % 10)+'0';
    str[9] = (questionSecondsLeft % 10)+'0';
    sendText(str);
  }
  // time is up work
  if (millis() > questionMsTimer) {
    mode = MODE_ROUND_END;
    rEnable = true;
    roundEndStatus = ROUND_END_STATUS_TIME_IS_UP;
    sendReset();
  }
  // skip work
  if (jbtnReserved.clickNotProcessed()){
    mode = MODE_ROUND_END;
    rEnable = true;
    roundEndStatus = ROUND_END_STATUS_SKIPPED;
    sendReset();
  }  
  // check answering player
  if (answeringPlayer != -1) {
    mode = MODE_ANSWERING;
    jbtnFalse.clickNotProcessed();
    jbtnTrue.clickNotProcessed();
    sendPlayer(answeringPlayer, 'S');      
    displayUpdateTimer = 0;
    ledsUpdateTimer = 0;
    ledsUpdateDelay = (answerSeconds * 1000) / ledstripLength;
    questionMsTimerLeft = questionMsTimer - millis();
    answerMsTimer = answerSeconds * 1000 + millis() - 1;
    rEnable = true;
  }
  // check all bad
  uint8_t cantAnswerPlayerCount = 0;
  for (uint8_t i = 0; i < 8; i++)
    if (!players[i].canAnswer)
      cantAnswerPlayerCount++;
  if (cantAnswerPlayerCount == activePlayerCount){
    mode = MODE_ROUND_END;
    rEnable = true;
    roundEndStatus = ROUND_END_STATUS_SKIPPED;
    sendReset();
  }
  // false start work
  falsestartWork();
}

uint8_t selectedPlayerIndex = 255;
uint8_t selectedPlayer = 255;
void modeQuestionCatSelectPlayer() {
  if (rEnable) {
    rEnable = false;
    selectedPlayerIndex = 255;
    selectedPlayer = 255;
    String str = "CAt.Sel.P.";
    sendText(str);
  }
  jbuttonsCheck();
  for (uint8_t i = 0; i < 8; i++) {
    if (jbtnPS[i].clickNotProcessed()) {
      selectedPlayerIndex = i;
    }
  }
  for (uint8_t i = 0; i < 8; i++) {
    if (players[i].playerIndex == selectedPlayerIndex) {
      if (selectedPlayer != i){
        if (selectedPlayer != 255)
          sendPlayer(selectedPlayer, 'R');
        selectedPlayer = i;
        sendPlayer(i, 'S');
        String str = "CAt.Sel.P. ";
        str[10] = selectedPlayerIndex + '1';
        sendText(str);
      }
    }
  }
  if (selectedPlayer != 255) {
    if (jbtnMaster.clickNotProcessed()){
      mode = MODE_ANSWERING;
      answeringPlayer = selectedPlayer;
      answeringPlayerOld = selectedPlayer;
      jbtnFalse.clickNotProcessed();
      jbtnTrue.clickNotProcessed();
      sendPlayer(answeringPlayer, 'S');
      displayUpdateTimer = 0;
      ledsUpdateTimer = 0;
      ledsUpdateDelay = (answerSeconds * 1000) / ledstripLength;
      questionMsTimerLeft = questionMsTimer - millis();
      answerMsTimer = answerSeconds * 1000 + millis();
      rEnable = true;
    }
  }
}

void answeredFalse() {
  players[answeringPlayer].canAnswer = false;
  sendReset();
  blinking(COLOR_ANSWER_FALSE);
  questionMsTimer = millis() + questionMsTimerLeft;
  displayUpdateTimer = 0;
  ledsUpdateTimer = 0;
  ledsUpdateDelay = (questionSeconds * 1000) / ledstripLength;
  answeringPlayer = -1;
  if (!isCatQuestion)
    mode = MODE_QUESTION_NORMAL;
  else {
    mode = MODE_ROUND_END;
    roundEndStatus = ROUND_END_STATUS_CAT_FALSE;
  }  
}

void answeredTrue() {
  mode = MODE_ROUND_END;
  answeringPlayerOld = answeringPlayer;
  answeringPlayer = -1;
  roundEndStatus = ROUND_END_STATUS_ANSWERED;
}

void modeAnswering() {
  if (rEnable){
    sendPlayer(answeringPlayer, 'S'); 
  }
  // display work
  if (millis() > displayUpdateTimer) {
    displayUpdateTimer = millis() + displayUpdateDelay;
    answerSecondsLeft = (answerMsTimer - millis()) / 1000;
    String str = "An.P     ";
    str[4] = players[answeringPlayer].playerIndex + '1';
    str[6] = (answerSecondsLeft / 100)+'0';
    str[7] = ((answerSecondsLeft / 10) % 10)+'0';
    str[8] = (answerSecondsLeft % 10)+'0';
    sendText(str);
  }
  // leds work
  if (millis() > ledsUpdateTimer) {
    ledsUpdateTimer = millis() + ledsUpdateDelay;
    uint8_t ledsNeedLight = ((((answerMsTimer - millis()) / (answerSeconds * 10)) * ledstripLength) / 100) + 1;
    sendToLeds(ledsNeedLight, COLOR_ANSWERING);
  }
  // buttons work
  jbuttonsCheck();
  if (jbtnTrue.clickNotProcessed()) {
    answeredTrue();
  }
  if (jbtnFalse.clickNotProcessed()) {
    answeredFalse();
  }
  // time is up work
  if (millis() > answerMsTimer) {
    sendReset();
    mode = MODE_JUDGEMENT;
    judgeMsTimer = millis() + (judgeSeconds * 1000) - 1;
    displayUpdateTimer = 0;
    ledsUpdateTimer = 0;
    ledsUpdateDelay = (judgeSeconds * 1000) / ledstripLength;
  }
  // false start work
  falsestartWork();
}

void modeJudgement() {
  // display work
  if (millis() > displayUpdateTimer) {
    displayUpdateTimer = millis() + displayUpdateDelay;
    judgeSecondsLeft = (judgeMsTimer - millis()) / 1000;
    String str = "Jd.P     ";
    str[4] = players[answeringPlayer].playerIndex + '1';
    str[6] = (judgeSecondsLeft / 100)+'0';
    str[7] = ((judgeSecondsLeft / 10) % 10)+'0';
    str[8] = (judgeSecondsLeft % 10)+'0';
    sendText(str);
  }
  // leds work
  if (millis() > ledsUpdateTimer) {
    ledsUpdateTimer = millis() + ledsUpdateDelay;
    uint8_t ledsNeedLight = ((judgeMsTimer - millis()) / (judgeSeconds * 10) * ledstripLength) / 100 + 1;
    sendToLeds(ledsNeedLight, COLOR_JUDGEMENT);
  }
  // buttons work
  jbuttonsCheck();
  if (jbtnTrue.clickNotProcessed()) {
    answeredTrue();
  }
  if (jbtnFalse.clickNotProcessed()) {
    answeredFalse();
  }
  // time is up work
  if (millis() > judgeMsTimer) {
    answeredFalse();
  }
  // false start work
  falsestartWork();
}

void modeRoundEnd() {
  switch (roundEndStatus) {
    case ROUND_END_STATUS_TIME_IS_UP:
      blinking(COLOR_ANSWER_FALSE);
      break;
    case ROUND_END_STATUS_SKIPPED:
      blinking(COLOR_JUDGEMENT);
      break;
    case ROUND_END_STATUS_ANSWERED:
      blinking(COLOR_ANSWER_TRUE);
      break;
    case ROUND_END_STATUS_CAT_FALSE:
      blinking(COLOR_ANSWER_FALSE);
      break;
  }
  mode = MODE_READY;
  rEnable = true;
}
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
void loop() {
  switch (mode) {
    case MODE_INITIALIZATION: modeInitialization(); break;
    case MODE_SETTINGS: modeSettings(); break;
    case MODE_READY: modeReady(); break;
    case MODE_QUESTION_NORMAL: modeQuestionNormal(); break;
    case MODE_QUESTION_CAT_SELECT_PLAYER: modeQuestionCatSelectPlayer(); break;
    case MODE_ANSWERING: modeAnswering(); break;
    case MODE_JUDGEMENT: modeJudgement(); break;
    case MODE_ROUND_END: modeRoundEnd(); break;
    case MODE_RANDOM_SELECTING_PLAYERS: modeRandomSelectingPlayers(); break;
    case MODE_RANDOM_DO: modeRandomDo(); break;
  }
  modeOld = mode;
}

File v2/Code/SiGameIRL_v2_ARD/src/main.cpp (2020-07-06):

#include <Arduino.h>
#include <FastLED.h>
#include <SPI.h>
#include <bitBangedSPI.h>
#include <MAX7219.h>
#include <Smoothed.h>

const uint16_t lightSensorDark = 400; // !!! SETUP THIS WITH YOUR PHOTORES
const uint16_t lightSensorLight = 700; // !!! SETUP THIS WITH YOUR PHOTORES
Smoothed <uint16_t> smoother; 

const uint8_t PIN_LIGHT_SENSOR = A1;
const uint8_t PIN_LEDSTRIP = A0;
const uint8_t PIN_MAX7219_DIN = 11;
const uint8_t PIN_MAX7219_CS = 12;
const uint8_t PIN_MAX7219_CLK = 13;
const uint8_t PIN_PLAYERS[8] = {6, 2, 3, 4, 7, 8, 9, 5}; // !!! SETUP THIS WITH YOUR SOLDERED BUTTONS

const uint8_t LEDSTRIP_LENGTH = 14; // !!! SETUP THIS WITH YOUR COUNT OF LEDS IN LEDSTRIP (COUNT MUST BE EVEN)
CRGB leds[LEDSTRIP_LENGTH];

const uint32_t ARD_BAUDTRATE = 115200;

MAX7219 display (1, PIN_MAX7219_CS, PIN_MAX7219_DIN, PIN_MAX7219_CLK);

const uint32_t colors[10] = {0xFF0000, 0x00FF00, 0x0000FF, 0xFFFFFF, 0x6600FF, 0xFFFF00, 0x111111, 0x555555, 0x999999, 0xBBBBBB};

#define MODE_INITIALIZATION 100
#define MODE_GAME 0
uint8_t mode = MODE_INITIALIZATION;
uint8_t playerState[8]; // 0 - off, 1 - on, 2 - blink, 3 - blink fast

uint32_t blinkTimer;
const uint32_t blinkDelay = 500; 
uint32_t blinkFastTimer;
const uint32_t blinkFastDelay = 50;
void playerWork() {
  for (uint8_t i = 0; i < 8; i++) {
    if (playerState[i] == 0)
      digitalWrite(PIN_PLAYERS[i], 0);
    else if (playerState[i] == 1)
      digitalWrite(PIN_PLAYERS[i], 1);
  }

  if (millis() > blinkTimer){
    blinkTimer = millis() + blinkDelay;
    for (uint8_t i = 0; i < 8; i++)
      if (playerState[i] == 2)
        digitalWrite(PIN_PLAYERS[i], !digitalRead(PIN_PLAYERS[i]));
  }
  if (millis() > blinkFastTimer){
    blinkFastTimer = millis() + blinkFastDelay;
    for (uint8_t i = 0; i < 8; i++)
      if (playerState[i] == 3)
        digitalWrite(PIN_PLAYERS[i], !digitalRead(PIN_PLAYERS[i]));
  }
}

uint16_t brightness;
uint16_t readBrightness() {
    brightness = analogRead(PIN_LIGHT_SENSOR);
    if (brightness < lightSensorDark)
      brightness = lightSensorDark;
    if (brightness > lightSensorLight)
      brightness = lightSensorLight;     
    brightness = map(brightness, lightSensorDark, lightSensorLight, 3, 255);
    smoother.add(brightness);
    return smoother.get();
}

uint32_t initSendTimer = 0;
const uint32_t initSendDelay = 1000;
void modeInitialization() {
  if (millis() > initSendTimer) {
    initSendTimer = millis() + initSendDelay;
    // sending ledstrip length
    Serial.print('L');
    uint8_t len = LEDSTRIP_LENGTH / 2;
    if (len < 100)
      Serial.print('0');
    else
      Serial.print(len / 100);
    
    if (len < 10)
      Serial.print('0');
    else
      Serial.print(len / 10 % 10);

    if (len < 1)
      Serial.print('0');
    else
      Serial.print(len % 10);
  }
  if (Serial.available() > 0) {
    char cmd = Serial.read();
    if (cmd == 'K') {
      mode = MODE_GAME;
    }  
  }
}

bool cmdComplite =  false;
char cmdbuf[20];
uint8_t cmdIndex = 0;
void modeGame() {
  playerWork();
  if (Serial.available() > 0) {
    cmdbuf[cmdIndex] = Serial.read();
    if (cmdbuf[cmdIndex] == '\r' || cmdbuf[cmdIndex] == '\n') {
      cmdComplite = true;
    }
    cmdIndex++;
  }
  if (cmdComplite) {
    cmdComplite = false;
    cmdIndex = 0;

    if (cmdbuf[0] == 'P') {
      uint8_t p = (uint8_t)cmdbuf[1];
      char subcmd = cmdbuf[2];
      if (subcmd == 'S'){
        playerState[p] = 1;
      } else if (subcmd == 'B') {
        playerState[p] = 2;
      } else if (subcmd == 'F') {
        playerState[p] = 3;
      } else if (subcmd == 'R') {
        playerState[p] = 0;
      }
    } else
    if (cmdbuf[0] == 'L') {
      for (uint8_t i = 0; i < LEDSTRIP_LENGTH; i++)
        leds[i] = 0;
      uint8_t needToLight = (uint8_t)cmdbuf[1];
      uint8_t colorR = (uint8_t)cmdbuf[2];
      uint8_t colorG = (uint8_t)cmdbuf[3];
      uint8_t colorB = (uint8_t)cmdbuf[4];

      uint8_t lM = LEDSTRIP_LENGTH / 2;
      if (needToLight > lM)
        needToLight = lM;
      for (uint8_t i = lM - needToLight; i < lM; i++)
        leds[i] = CRGB(colorR, colorG, colorB);
      for (uint8_t i = lM; i < needToLight + lM; i++)
        leds[i] = CRGB(colorR, colorG, colorB);

      FastLED.setBrightness(readBrightness());
      FastLED.show();
    } else
    if (cmdbuf[0] == 'T') {
      display.sendString("        ");
      display.setIntensity(readBrightness() / 18);
      uint8_t dispPos = 0;
      uint8_t charIndex = 1;
      bool reading = true;
      char charNow;
      char charNext;
      while (reading) {
        if (dispPos == 0) {
          charNow = cmdbuf[charIndex++];
          charNext = cmdbuf[charIndex++]; 
          if (charNext == '.') {
            display.sendChar(dispPos, charNow, true);
            charNext = cmdbuf[charIndex++];
            dispPos++;
          } else {
            display.sendChar(dispPos, charNow, false);
            dispPos++;
          }
        } else {
          charNow = charNext;
          charNext = cmdbuf[charIndex++]; 
          if (charNext == '.') {
            display.sendChar(dispPos, charNow, true);
            charNext = cmdbuf[charIndex++]; 
            dispPos++;
          } else {
            display.sendChar(dispPos, charNow, false);
            dispPos++;
          }
        }
        if (dispPos == 8)
          reading = false;
        if (charNext == '\n' || charNext == '\r')
          reading = false;
      }
    } else
    if (cmdbuf[0] == 'R') {
      display.sendString("        "); 
      for (uint8_t i = 0; i < LEDSTRIP_LENGTH; i++) {
        leds[i] = 0;
      }
      FastLED.show();
      for (uint8_t i = 0; i < 8; i++) {
        playerState[i] = 0;
      }
    }
  }  
}

void setup() {
  pinMode(PIN_LIGHT_SENSOR, INPUT);
  for (uint8_t i = 0; i < 8; i++)
    pinMode(PIN_PLAYERS[i], OUTPUT);
  Serial.begin(ARD_BAUDTRATE);
  FastLED.addLeds<WS2812B, PIN_LEDSTRIP, GRB>(leds, LEDSTRIP_LENGTH);
  display.begin();
  display.setIntensity(5); // 15 max
  // test
  for (uint8_t i = 0; i < 8; i++)
    digitalWrite(PIN_PLAYERS[i], 1);
  for (uint8_t i = 0; i < LEDSTRIP_LENGTH; i++)
    leds[i] = 0x11111111;
  FastLED.show();
  for (uint8_t j = 0; j < 10; j++) {
    for (uint8_t i = 0; i < 8; i++) {
      display.sendChar(i, j+'0', true);
    }
    delay(50);
  }
  for (uint8_t i = 0; i < 8; i++) {
    display.sendChar(i, '8', true);
  }
  delay(500);
  for (uint8_t i = 0; i < LEDSTRIP_LENGTH; i++)
    leds[i] = 0;
  FastLED.show();
  display.sendString("        ");
  for (uint8_t i = 0; i < 8; i++)
    digitalWrite(PIN_PLAYERS[i], 0);
  // test end
	smoother.begin(SMOOTHED_EXPONENTIAL, 10);
  smoother.clear();
}

void loop() {
  switch (mode) {
    case MODE_INITIALIZATION: modeInitialization(); break;
    case MODE_GAME: modeGame(); break;
  }
}

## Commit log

2020-06-23 Assembled added
2020-06-24 Fixed judgebuttons false work. Added Cat
    Fixed judgebuttons false work
    Added cat-question work
    [main.cpp]
2020-06-28 start creating v2
    [SiGame.fzz, SiGame_Button.dxf, SiGame_Button.obj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]
2020-06-28 v2 added scheme
    [SiGame2.fzz]
2020-06-28 v2 Updated scheme
    [SiGame2.fzz]
2020-06-28 Updated Scheme
    [SiGame2.fzz]
2020-07-02 working scheme
    [SiGame2.fzz]
2020-07-04 v2 upload
    [SiGame2.fzz]
2020-07-06 Fixed indicator when answering
    [main.cpp]
